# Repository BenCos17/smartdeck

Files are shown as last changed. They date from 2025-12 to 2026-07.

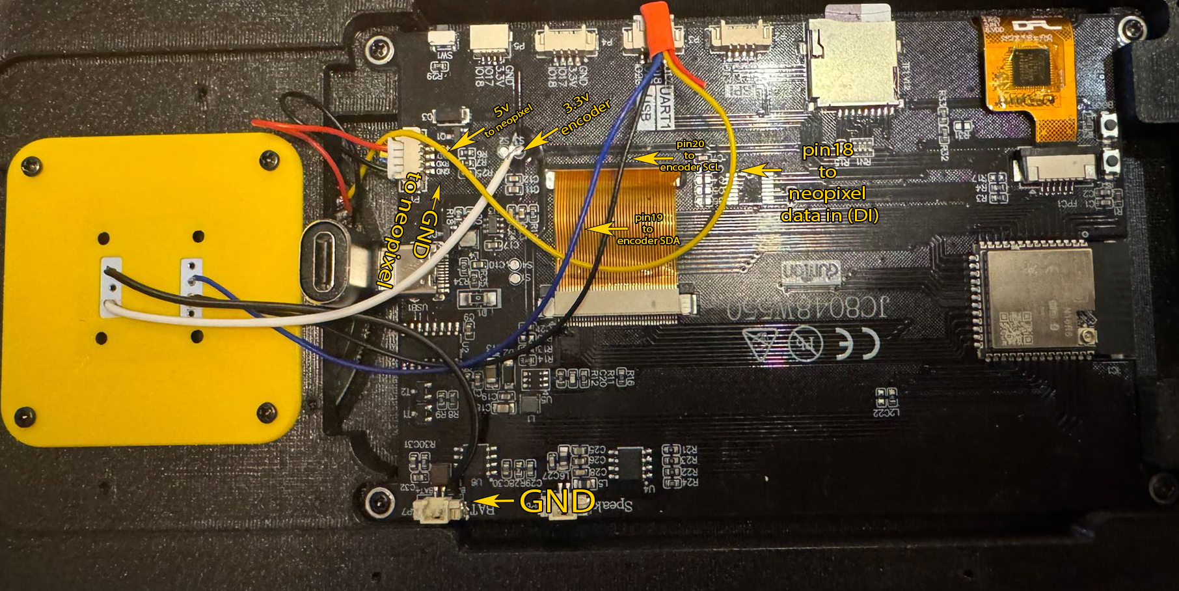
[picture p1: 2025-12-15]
wiring_scheme.jpg

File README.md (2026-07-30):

# SmartDeck v2.5.1

Ekran görüntüsü 2025-12-06 211021

<div align="center">

**A powerful, customizable macro deck application for Windows**



</div>

---

## 📖 Overview

SmartDeck transforms ESP32-based touch screens into powerful macro control panels. Create custom buttons to execute keyboard shortcuts, launch applications, control media, run scripts, build multi-action sequences, and much more. Perfect for streamers, content creators, developers, and power users.

---

## 🖥️ Supported Devices

| Device | Description |
|---|---|
| **ESP32 TouchDown** | 3.5" 480×320 ILI9488 + FT6236, ESP32-WROOM-32D ([Tindie](https://www.tindie.com/products/dustinwattsnl/esp32-touchdown/)) — **default in this fork** |
| **Guition JC8048W550** | 5" 800×480 Capacitive, ESP32-S3 ([AliExpress](https://www.aliexpress.us/item/3256806529267135.html)) |

> This fork ships with **`ESP32_TOUCHDOWN`** enabled in `JC8048W550/Arduino/smart_deck/config.h`. Set resolution to **480×320** in the SmartDeck desktop app.

> ⚠️ **Backlight (TouchDown V1.1)**: Bridge the backlight jumper to **GPIO32** on the board back if you want PWM brightness control. Without it, the screen stays on at full brightness.

> ⚠️ **JC8048W550**: SmartDeck is also optimized for the **Guition JC8048W550** display. 3D printed enclosure files and rotary encoder mounting are tailored for that device.

### 🔧 Adapting for Other Displays

SmartDeck is open source and can be adapted for other ESP32-based displays. To use a different screen:

1. Download the Arduino source files from this repository
2. Install **ESP32 Board Package v2.0.17** in Arduino IDE
3. Modify the following files for your display:
   - `config.h` - Uncomment your board (`ESP32_TOUCHDOWN`, `ESP32_JC8048W550`, etc.), set resolution and pins
   - `Arduino_GFX_dev_device.h` - Display driver and initialization settings
4. Compile and upload to your device

### ESP32 TouchDown quick start

1. Open `JC8048W550/Arduino/smart_deck/smart_deck.ino` in Arduino IDE
2. Board: **ESP32 Dev Module**, USB CDC disabled, 115200 baud
3. `config.h` should have `#define ESP32_TOUCHDOWN` (already set in this fork)
4. Upload firmware, then in SmartDeck app set device resolution to **480×320**

> 💡 Community contributions for other displays are welcome! If you successfully adapt SmartDeck for a different screen, consider submitting a PR.

---

## 🛒 Bill of Materials (BOM)

> ⚠️ **Note**: The following parts are required to build the complete SmartDeck with rotary encoder. The display itself is sold separately - see "Supported Devices" above.

| Part | Description | Link |
|---|---|---|
| **Guition JC8048W550** | 5" ESP32-S3 Capacitive Display (Main unit) | [AliExpress](https://www.aliexpress.us/item/3256806529267135.html) |
| **AS5600 Magnetic Encoder** | Rotary encoder module with magnet included | [AliExpress](https://tr.aliexpress.com/item/1005009252608246.html) |
| **NeoPixel RGB LED Ring** | 16-LED WS2812 ring (53mm inner, 66mm outer) | [AliExpress](https://tr.aliexpress.com/item/33039423907.html) |
| **25×52×15 Ball Bearing** | Deep-groove ball bearing for smooth rotation | [Link](https://simmering.pl/en/deep-groove-ball-bearings/28183-6205-zz-nectech-25x52x15-deep-groove-ball-bearing.html) |
| **6×3mm Neodymium Magnets** | Round magnets for encoder (80-150 pcs) | [Temu](https://www.temu.com/tr/80-150pcs-6x3mm-round-magnets-strong-neodymium--mini-refrigerator-whiteboard-magnets-durable-metal-construction-for-office-kitchen-fridge-org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) |
| **1.25mm to Dupont Cable** | 4-pin cable for 5V, GND, external pins (2 pcs) | [AliExpress](https://tr.aliexpress.com/item/1005006621865408.html) |
| **90° USB-C Adapter** | Right-angle Type-C male to female (40Gbps preferred) | [AliExpress](https://tr.aliexpress.com/item/1005006997812852.html) |
| **Screws** | Assorted screws for assembly | [Temu](https://www.temu.com/goods.html?_bg_fs=1&goods_id=601099519474986&sku_id=17592228808109) / [AliExpress](https://www.aliexpress.us/item/3256804422855415.html) |
| **Cables & Wires** | General-purpose wires for connections | — |
| **Soldering Iron** | For wiring and assembly | — |
| **Tape** | Insulation tape for cable management | — |

### 🖨️ 3D Printed Parts

STL files for the enclosure are available in the `/3d_print_files` folder.

---
WhatsApp Image 2025-12-06 at 21 16 12

## ✨ Key Features

### 🎮 **13 Button Action Types**

Ekran görüntüsü 2025-12-06 211035

| Action | Description |
|---|---|
| **HotKey** | Keyboard shortcuts (CTRL+C, ALT+TAB, etc.) |
| **Page** | Navigate between button pages |
| **Toggle** | Two-state buttons with visual feedback |
| **Text** | Type text with optional realistic typing simulation |
| **Open App** | Launch applications |
| **Timer** | Countdown timers with notifications |
| **Script** | Execute command-line scripts |
| **Website** | Open URLs in browser |
| **Media** | Play/pause, volume, track controls |
| **Mouse** | Click, double-click, move, drag |
| **Counter** | Increment/decrement with long-press reset |
| **Sound** | Play audio files with volume control |
| **Multi-Action** | Chain multiple actions in sequence |

### 🔗 **Multi-Action Builder**

Create complex macros by chaining actions together:

- **Delay** - Wait between actions (ms precision)
- **HotKey** - Press key combinations
- **Text** - Type text strings
- **Open App** - Launch programs
- **Website** - Open URLs
- **Script** - Run commands
- **Media** - Media controls
- **Sound** - Play audio
- **Mouse** - Mouse operations
- **Go to Page** - Switch pages

Drag & drop interface for easy sequence building.

### 🎛️ **Rotary Encoder Support**

- Volume control, scrolling, zooming
- Customizable actions for clockwise/counter-clockwise
- LED color feedback per page
- Adjustable sensitivity
- Modifier key combinations (ALT+Scroll, CTRL+Scroll)

### 🎨 **Full Customization**

- **100,000+ Icons** via Iconify integration
- **Local Images** with built-in crop & scale editor
- **Custom Colors** for background, text, icon, stroke, shadow
- **Text Positioning** - Top, middle, bottom alignment
- **Per-Button Styling** - Every button fully customizable

### 🌍 **7 Languages**

English • Türkçe • Deutsch • Español • Français • 日本語 • 中文

### ⚡ **Smart Features**

- **Auto-Connect** - Automatic device detection and reconnection
- **Smart Upload** - Only uploads changed files (faster sync)
- **App-Based Pages** - Auto-switch pages based on active application
- **Sleep/Wake** - Configurable screen timeout with tap-to-wake
- **Preview Mode** - Test buttons without device (right-click → Test)
- **Undo/Redo** - Full history with up to 50 steps
- **Drag & Drop** - Reorder buttons and pages intuitively
- **System Tray** - Minimize to tray, start minimized option

### 📦 **Built-in Presets**

Ready-to-use shortcuts for:

- Adobe Suite (Photoshop, Premiere, After Effects, Illustrator)
- 3D Software (Blender, Cinema 4D)
- DAWs (FL Studio, DaVinci Resolve)
- Streaming (OBS Studio)
- Development (VS Code)
- General (Chrome, Discord, VLC, Spotify)

---

## 🚀 Getting Started

### Requirements

- Windows 10/11
- Guition JC8048W550 (or compatible ESP32 display)

### Installation

1. Download latest release from [Releases](https://github.com/ozancs/smartdeck/releases)
2. Run installer
3. Connect device via USB
4. Flash firmware using **⚡ Install Firmware** button
5. Start creating!

---

## 🔧 How It Works

```
┌─────────────────┐     USB/Serial     ┌──────────────────┐
│  SmartDeck App  │ ◄───────────────► │  ESP32 Device    │
│  (Electron)     │    115200 baud     │  (Touch Screen)  │
└─────────────────┘                    └──────────────────┘
        │                                       │
        ▼                                       ▼
   Button Config                          Display & Touch
   Action Execute                         Button Rendering
   Serial Commands                        Touch Events
```

### Connection Flow

1. App scans for COM ports automatically
2. Sends PING, waits for PONG handshake
3. Syncs configuration to device
4. Receives touch events in real-time
5. Auto-reconnects on disconnect

---

## ⚙️ Settings

Ekran görüntüsü 2025-12-06 211042

| Category | Options |
|---|---|
| **Device** | Name, resolution, grid size, colors |
| **Screen** | Brightness, sleep timeout |
| **Knob** | LED colors per page, sensitivity, actions |
| **Startup** | Launch with Windows, start minimized |
| **Close** | Exit or minimize to tray |
| **Sound** | Toggle sound, timer notification |
| **Language** | 7 language options |

---

## 🛠️ Firmware Installation

1. Click **⚡ Install Firmware**
2. Select screen model
3. Choose COM port
4. Click **START FLASHING**
5. Wait for completion (~60 seconds)

> ⚠️ Do not unplug during flashing!

---

## 📝 What's New in v2.5.1

- ✅ Multi-Action Builder with drag & drop
- ✅ Rotary encoder support with LED feedback
- ✅ Preview/Test mode (right-click menu)
- ✅ Start minimized to system tray
- ✅ Unicode path support (Turkish characters, etc.)
- ✅ App-based automatic page switching
- ✅ Smart upload (only changed files)
- ✅ Serial debug monitor
- ✅ Improved auto-reconnect stability
- ✅ Full internationalization for all UI elements

---

## 🤝 Contributing

Contributions welcome! 

- **Bug Reports**: Open an issue with reproduction steps
- **Feature Requests**: Describe your idea in an issue
- **New Device Support**: Fork, adapt firmware, submit PR

## 📄 License

This project is open source. See [LICENSE](LICENSE) for details.

## 🙏 Acknowledgments

- [Iconify](https://iconify.design/) - Icon library
- [NirCmd](https://www.nirsoft.net/utils/nircmd.html) - Audio control utilities
- [Electron](https://www.electronjs.org/) - Application framework
- [@jitsi/robotjs](https://github.com/nicktgr15/robotjs) - Keyboard/mouse automation

---

<div align="center">

**[⬇️ Download](https://github.com/ozancs/smartdeck/releases)** • **[🐛 Report Bug](https://github.com/ozancs/smartdeck/issues)** • **[💡 Request Feature](https://github.com/ozancs/smartdeck/issues)**

Made with ❤️ by [ozancs](https://github.com/ozancs)

</div>

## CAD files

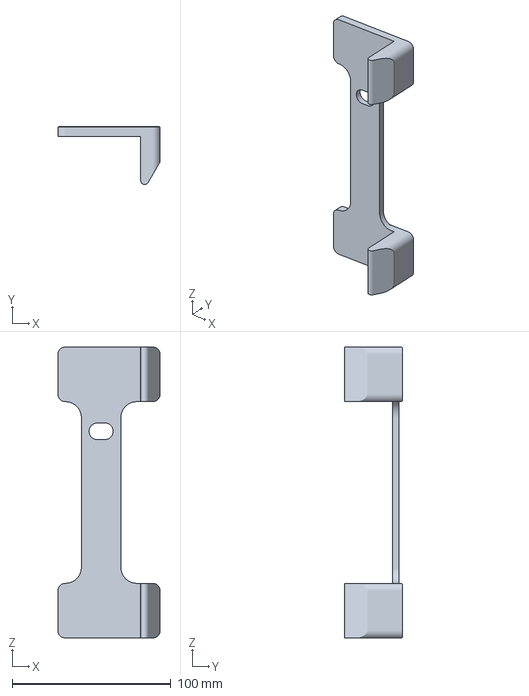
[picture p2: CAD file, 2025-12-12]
3d_print_files/60_DEGREE_LEG.3mf
64.5 x 36.7 x 183.5 mm

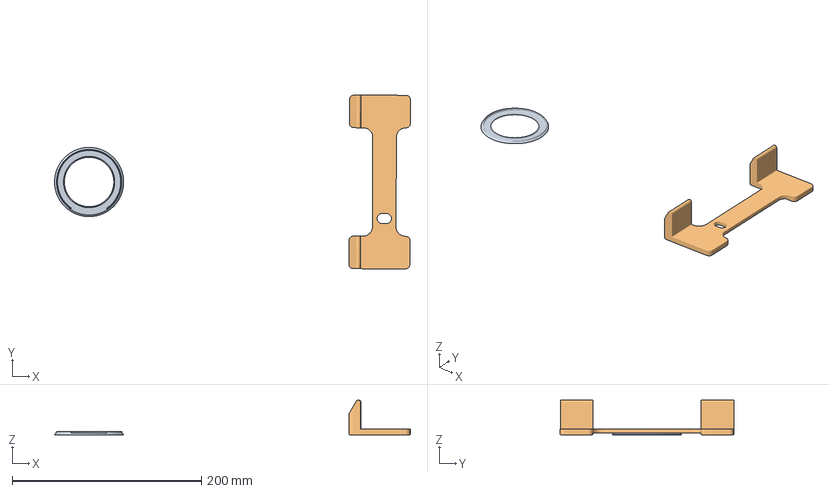
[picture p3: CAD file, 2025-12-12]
3d_print_files/diffuser.3mf
376.3 x 183.7 x 36.7 mm
diffuser
30degree_holder

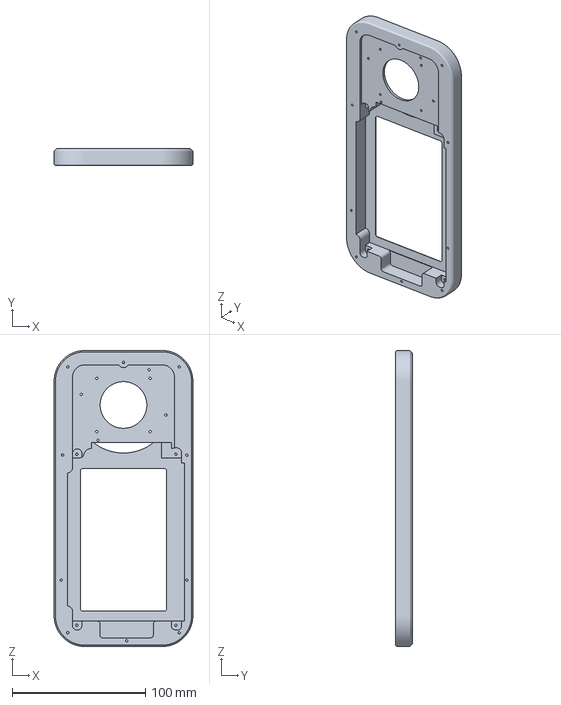
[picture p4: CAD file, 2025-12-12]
3d_print_files/Body.3mf
104.0 x 13.0 x 222.0 mm

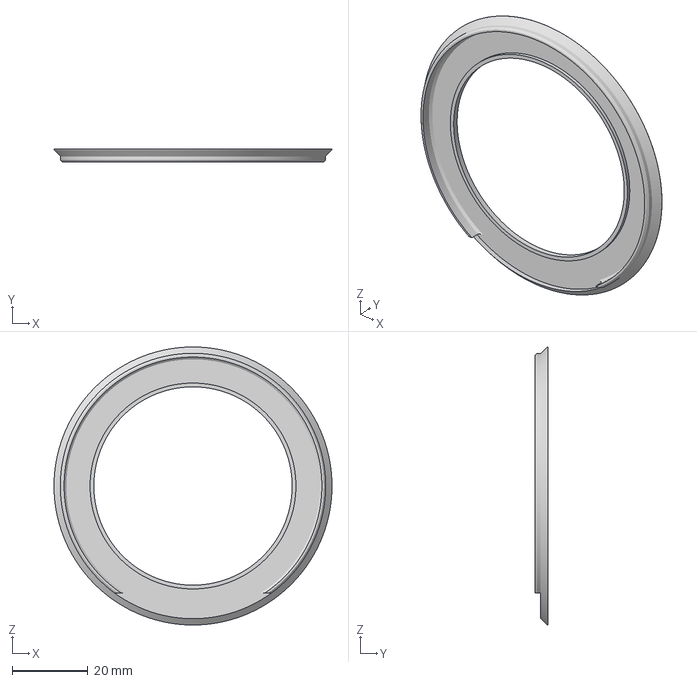
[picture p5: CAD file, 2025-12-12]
3d_print_files/diffuser_0.4mm.3mf
73.2 x 3.50 x 73.2 mm

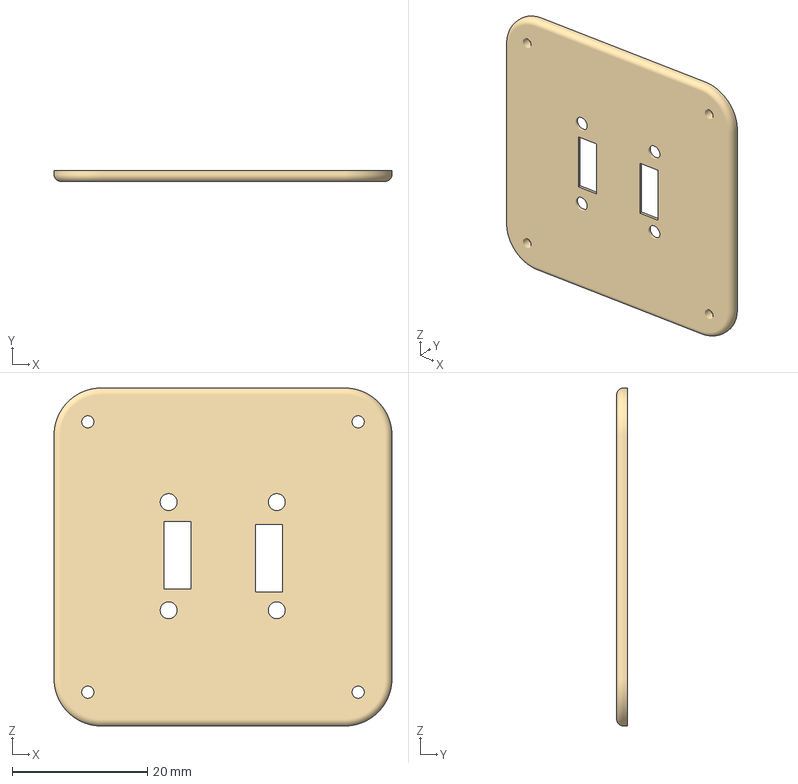
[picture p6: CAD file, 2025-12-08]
3d_print_files/as5600_holder.3mf
50.0 x 1.60 x 50.0 mm

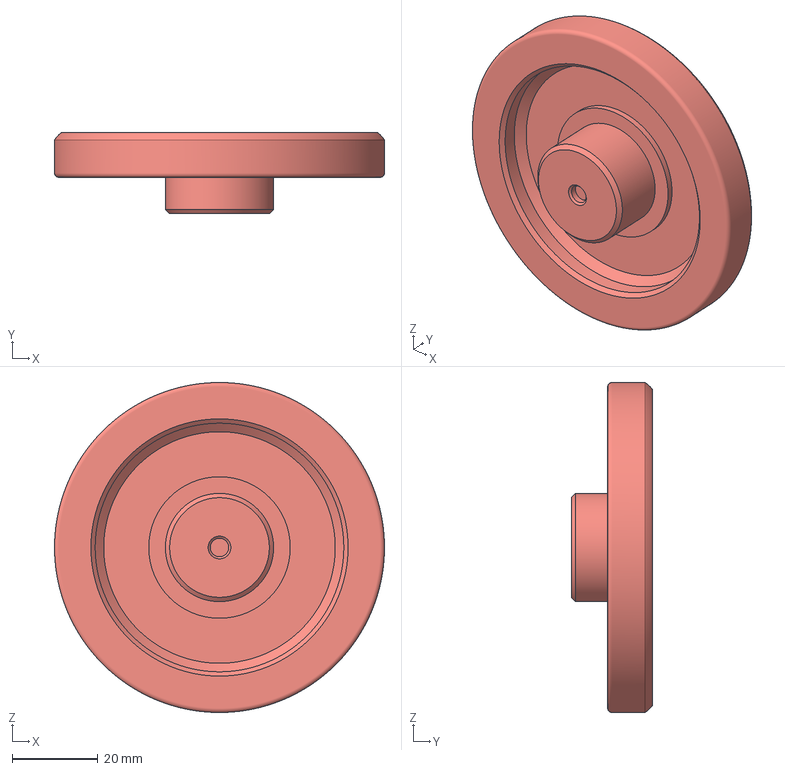
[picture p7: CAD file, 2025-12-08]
3d_print_files/Knob.3mf
77.0 x 19.0 x 77.0 mm

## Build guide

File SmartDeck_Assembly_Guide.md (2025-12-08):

# SmartDeck Hardware Assembly Guide

## Prerequisites

### 3D Printed Parts
Print all parts from the `3D Print Files` folder with the following settings:
- **Supports:** Enabled (required for overhangs)
- **Infill:** 15-20% recommended
- **Layer Height:** 0.2mm or finer for better tolerances

**Parts List:**
- Main Body (1x)
- Knob (1x)
- AS5600 Holder (1x)
- Back Cover (1x)
- Stand/Feet (optional, 1x)

### Bill of Materials

| Item | Description | Source |
|---|---|---|
| 25×52×15 Ball Bearing | Deep-groove ball bearing | [Link](https://simmering.pl/en/deep-groove-ball-bearings/28183-6205-zz-nectech-25x52x15-deep-groove-ball-bearing.html) |
| AS5600 Magnetic Encoder Module | Includes matching magnet | [Link](https://tr.aliexpress.com/item/1005009252608246.html) |
| NeoPixel RGB LED Ring (16 LEDs) | WS2812-compatible, ~53mm inner / ~66mm outer diameter | [Link](https://tr.aliexpress.com/item/33039423907.html) |
| 90° Type-C Male to Female Adapter | Prefer "40Gbps" printed version | [Link](https://tr.aliexpress.com/item/1005006997812852.html) |
| 6×3mm Round Neodymium Magnets | 80-150 pieces for back cover and stand | [Link](https://www.temu.com/tr/80-150pcs-6x3mm-round-magnets-strong-neodymium--mini-refrigerator-whiteboard-magnets-durable-metal-construction-for-office-kitchen-fridge-org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) |
| 1.25mm to Dupont 2.54 Terminal Cable (4-Pin) | For display connector routing (optional) | [Link](https://tr.aliexpress.com/item/1005006621865408.html) |
| M2 Screws | Various lengths: M2×3mm, M2×4mm, M2×5mm | [Link 1](https://www.temu.com/goods.html?_bg_fs=1&goods_id=601099519474986&sku_id=17592228808109) / [Link 2](https://www.aliexpress.us/item/3256804422855415.html) |
| Soldering Iron | For wiring connections | — |
| Cables/Wires | For external connections | — |
| Tape | Electrical or general-purpose | — |

---

## Assembly Instructions

### Step 1: Prepare the Knob Assembly

1. **Install the ball bearing:**
   - Press the **25×52×15mm ball bearing** into the knob print until it sits flush.
   - It should be a snug fit; apply even pressure around the edges.

2. **Attach the magnet:**
   - Locate the small hole on the underside of the knob (center).
   - Take the **magnet included with the AS5600 module** and apply a small amount of adhesive to its back only (the side that will contact the knob).
   - **Important:** Keep the face of the magnet that will face the sensor completely free of adhesive. Any glue residue on this surface can cause signal fluctuations and erratic readings.
   - Press the magnet into the hole and allow it to cure.

---

### Step 2: Prepare the SD Card

The ESP32 display requires a FAT32-formatted SD card.

1. Insert your SD card into your computer.
2. Format it as **FAT32**.

> **Note for large capacity cards (64GB+):** Windows cannot natively format cards larger than 32GB as FAT32. Use the free tool **guiformat** from:
> http://ridgecrop.co.uk/index.htm?guiformat.htm

3. Once formatted, insert the SD card into the display's SD card slot.

---

### Step 3: Mount the Display

1. Attach the **90° Type-C adapter** to the display's USB-C port.
2. Place the display into the main body with the USB connector oriented toward the knob side.
3. Align the four mounting holes and secure with **M2×4mm or M2×5mm screws** (the screw holes are approximately 5mm deep).

---

### Step 4: Install the NeoPixel LED Ring

1. **Solder wires to the LED ring:**
   - Solder individual wires to the **5V**, **GND**, and **DI (Data In)** pads.
   - Cut wires longer than needed; you can trim them later.

2. **Mount the ring:**
   - Route the wires through the cable channel in the main body.
   - Press the **16-LED NeoPixel ring** into the knob-side recess, aligning the four screw holes.
   - Secure with **M2×3mm or M2×3.5mm screws** (hole depth is ~7.5mm; do not exceed this).

---

### Step 5: Prepare and Install the AS5600 Encoder Module

1. **Solder wires to the AS5600 module:**
   - Attach wires to: **SDA**, **SCL**, **VCC**, and **GND** pads.

2. **Mount the module in its holder:**
   - Insert the AS5600 module into the **AS5600 Holder** print with wires passing through the designated holes.
   - The fit should be snug. If there's slight play, use a small amount of adhesive to secure it.

3. **Install the holder in the main body:**
   - Position the holder inside the main body so the **sensor faces the knob hole** (where the magnet will be).
   - Secure with four **M2×5mm screws** (hole depth is ~7.5mm).

---

### Step 6: Clean the Main Body and Install the Knob

> **Important:** Before proceeding, thoroughly clean all support material residue from the main body, especially inside the bearing seat. Leftover supports can prevent proper seating and cause friction.

1. Take the knob assembly (with bearing and magnet installed).
2. Align it with the bearing seat on the main body.
3. Press firmly until the bearing snaps into place. It should rotate smoothly.

---

### Step 7: Prepare the Back Cover

1. Remove all support material from the back cover print.
2. Insert **6×3mm neodymium magnets** into each magnet slot.
   - **Critical:** Ensure all magnets have the **same polarity orientation** (e.g., all north-facing up).
   - Some holes may be tight due to printer tolerances; apply gentle pressure.
   - Some may be loose; proceed to the next step.
3. Once all magnets are seated, cover them with a strip of tape to prevent them from dislodging.

---

### Step 8: Prepare the Stand (Optional)

1. Insert **6×3mm neodymium magnets** into the stand's magnet slots.
2. **Critical:** These magnets must be in the **opposite orientation** to those in the back cover (so they attract, not repel).
3. Double-check each magnet before fully seating it. A reversed magnet will cause the stand and body to repel each other.
4. Secure with tape if needed.

---

### Step 9: Wiring Connections

You have two options for connecting the components to the display's GPIO pins:

| Method | Pros | Cons |
|---|---|---|
| **Soldering directly to pins** | Most reliable, clean | Requires soldering skill |
| **Dupont connectors** (included with display) | No soldering needed | Bulkier, may come loose |

**Recommended:** Direct soldering for best long-term reliability.

If you choose the Dupont connector method, you'll need to connect your soldered component wires to the Dupont cables. You can do this by twisting the wires together—this is the quickest solution but also the least clean. For a more secure connection, solder the component wires directly to the Dupont cable ends or use crimp connectors.

#### AS5600 Encoder Connections

| AS5600 Pin | ESP32 GPIO | Notes |
|---|---|---|
| SDA | Pin 19 | I²C Data |
| SCL | Pin 20 | I²C Clock |
| VCC | 3.3V | **Do not use 5V** |
| GND | GND | |

#### NeoPixel LED Ring Connections

| NeoPixel Pin | ESP32 GPIO | Notes |
|---|---|---|
| DI (Data In) | Pin 18 | Data signal |
| 5V | 5V | Power |
| GND | GND | |

---

### Step 10: Final Assembly

1. Route all wires neatly inside the enclosure.
2. Align the **back cover** with the USB cutout facing the correct direction.
3. Secure with **M2×5mm screws** into the main body.
4. Attach the **stand** to the back cover—the magnets should snap together satisfyingly.

---

## Software Setup

1. Connect SmartDeck to your computer via USB.
2. Download and install the **SmartDeck** application from:
   
   👉 **https://github.com/ozancs/smartdeck/releases**

3. Launch the application.
4. Click **"Install Firmware"** in the bottom-right corner.
5. Select your device's **COM port** from the dropdown.
6. Click **Install** to flash the firmware to your ESP32 display.
7. Once complete, configure your buttons, LED colors, themes, and macros.

---

**Enjoy your SmartDeck!**

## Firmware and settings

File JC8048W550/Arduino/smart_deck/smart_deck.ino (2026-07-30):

/* * OZAN'S WEB DECK - v4.0 (Serial and ESP-NOW Mode)
 * * This version does not include Wi-Fi and BLE. Communication is done via USB Serial Port
 * or ESP-NOW (Dongle Mode).
 * */
#ifndef BLACK
#define BLACK 0x0000
#endif

#ifndef WHITE
#define WHITE 0xFFFF
#endif


#include "config.h"

// Receiver MAC for ESP-NOW dongle mode
uint8_t receiver_mac[] = RECEIVER_MAC;

#include "touch_panel.h"

// --- REMOVED: <BleKeyboard.h> ---
// --- REMOVED: <WiFi.h>, <AsyncTCP.h>, <ESPAsyncWebServer.h>, <ESPmDNS.h> ---

#include <vector>
#include <map>
#include <string>
#include <set>
#include <ArduinoJson.h>

/* GFX Libraries */
#include <Arduino_GFX_Library.h>
#include "Arduino_GFX_dev_device.h"
#ifndef GFX_DEV_DEVICE
#include "Arduino_GFX_pins.h"
#include "Arduino_GFX_databus.h"
#include "Arduino_GFX_display.h"
#endif
#ifdef ESP32
#undef F
#define F(s) (s)
#endif

/* SD Card Libraries */
#include "FS.h"
#include "SD.h"
#include <SPI.h>

#include <Adafruit_NeoPixel.h>

// NeoPixel object
Adafruit_NeoPixel strip(LED_COUNT, LED_PIN, NEO_GRB + NEO_KHZ800);


/* --- TJpgDec Library --- */
#include <TJpg_Decoder.h>

/* --- Weather Icons for Sleep Screen --- */
#include "weather_icons.h"

/* --- NEW: For Saving Settings --- */
#include <Preferences.h>
Preferences preferences;

/* --- NEW: Brightness and Sleep Variables --- */
int current_brightness = 100;                    // 0-100 range
bool sleep_enabled = false;                      // Is sleep mode enabled?
unsigned long sleep_timeout_ms = 1 * 60 * 1000;  // Default 5 minutes
unsigned long last_activity_time = 0;            // Last activity time
bool is_sleeping = false;                        // Currently sleeping?

/* --- Clock for Sleep Mode (millis-based tracking) --- */
int current_hour = 12;
int current_minute = 0;
int current_second = 0;
unsigned long last_clock_update_millis = 0;  // Last time we updated the clock
bool clock_initialized = false;              // Has time been set at least once?

/* --- Weather Data for Sleep Screen --- */
bool weather_available = false;     // Do we have valid weather data?
int weather_temp = 0;               // Temperature (integer)
int weather_code = 0;               // WMO weather code
bool weather_is_day = true;         // Is it daytime?
bool weather_is_celsius = true;     // Temperature unit (true=C, false=F)
char weather_description[32] = "";  // Weather description from app (translated)
char weather_city[32] = "";         // City name from app

/* --- Deep Sleep Mode (screen & LED off) --- */
bool deep_sleep_enabled = false;                       // Is deep sleep enabled?
unsigned long deep_sleep_timeout_ms = 30 * 60 * 1000;  // Default 30 min after dim
unsigned long dim_start_time = 0;                      // When did dim mode start?
bool is_deep_sleeping = false;                         // Currently in deep sleep?

/* --- Dim LED Animation --- */
// 0=off, 1=breathing, 2=rainbow, 3=pulse, 4=comet, 5=sparkle
uint8_t dim_led_animation = 0;
unsigned long dim_led_last_update = 0;
uint16_t dim_led_step = 0;
uint8_t dim_led_hue = 0;

// Rainbow animation color
uint8_t fade_color_r = 255, fade_color_g = 0, fade_color_b = 0;

// Sparkle state - tracks which LEDs are blinking and their phase
uint8_t sparkle_brightness[LED_COUNT];
bool sparkle_active[LED_COUNT];

#include <Wire.h>
#include <AS5600.h>

AS5600 as5600(&Wire);

// Knob LED settings
int knob_old_angle = 0;
int knob_threshold = KNOB_THRESHOLD;
unsigned long lastKnobEvent = 0;
uint8_t knob_r = 255, knob_g = 255, knob_b = 255;  // Default: White
int knob_tail_length = 5;
uint8_t led_brightness = 255;  // LED brightness (0-255)


// --- CONDITIONAL LIBRARY INCLUSION (Only for Dongle Mode) ---
#if DONGLE_MODE == 1
#include <WiFi.h>  // Required for ESP-NOW
#include <esp_now.h>
#endif
// --- END ---

// Touch Panel
#if defined(ESP32_TOUCHDOWN)
TouchPanel tp(TOUCH_SDA, TOUCH_SCL, TOUCH_INT, TOUCH_WIDTH, TOUCH_HEIGHT);
#else
TouchPanel tp(TOUCH_SDA, TOUCH_SCL, TOUCH_INT, TOUCH_RST, TOUCH_WIDTH, TOUCH_HEIGHT);
#endif

/*******************************************************************************
 * Global Variables
 ******************************************************************************/
uint32_t screenWidth = SCREEN_WIDTH;
uint32_t screenHeight = SCREEN_HEIGHT;

/* REMOVED: BleKeyboard bleKeyboard; */
/* REMOVED: AsyncWebServer server(80); */
/* REMOVED: String ip_address = "Connecting..."; */
/* REMOVED: File uploadFile; */

String serial_cmd_buffer = "";
bool serial_cmd_ready = false;

DynamicJsonDocument doc(16384);
uint8_t current_page = 0;
uint16_t theme_bg_color_rgb565;
uint16_t theme_btn_color_rgb565;
uint16_t theme_stroke_color_rgb565 = 0x8410;
uint16_t theme_empty_btn_color_rgb565 = 0x3186;
uint16_t theme_click_stroke_color_rgb565 = 0x05BF;
uint16_t theme_text_color_rgb565;
uint16_t theme_shadow_color_rgb565;

struct ButtonInfo {
  int x;
  int y;
  int w;
  int h;
  String action;
  String value;
  bool defined = false;
};
std::vector<ButtonInfo> current_buttons;

enum TimerState {
  TIMER_INACTIVE,
  TIMER_RUNNING,
  TIMER_FINISHED
};
struct TimerInfo {
  TimerState state = TIMER_INACTIVE;
  int duration = 0;
  unsigned long startTime = 0;
  int lastSeconds = -1;  // Last displayed seconds
};

// Global map for running timers (survives page changes)
// Key: page * 100 + btn_idx
std::map<int, TimerInfo> running_timers;

// Global map for finished timers (waiting for auto-reset on other pages)
// Key: page * 100 + btn_idx, Value: {finish_time, duration}
struct FinishedTimerInfo {
  unsigned long finishTime;
  int duration;
};
std::map<int, FinishedTimerInfo> finished_timers;

struct CounterInfo {
  long currentValue = 0;        // Current counter value
  long startValue = 0;          // Start value (for reset)
  String action = "increment";  // "increment" or "decrement"
};
std::vector<CounterInfo> current_counters;  // <-- NEWLY ADDED

// --- NEW: TOGGLE INFO ---
struct ToggleInfo {
  bool state = false;         // false = OFF (State A), true = ON (State B)
  uint16_t onColor = 0x07E0;  // Default Green (RGB565)
};
std::vector<ToggleInfo> current_toggles;

std::vector<TimerInfo> current_timers;

bool was_touched = false;
int last_touched_button_index = -1;
unsigned long touch_start_time = 0;  // NEW: For detecting long press
bool long_press_triggered = false;   // NEW: Was long press triggered?

typedef struct {
  int x;
  int y;
  int maxWidth;
  int maxHeight;
  int x_offset;
  int y_offset;
  int radius;
} JpegDrawInfo;

JpegDrawInfo jpegInfo;


// --- FUNCTION PROTOTYPES (Prevents compiler errors) ---
void draw_page(int page_index);
void draw_single_button(int btn_index);
void checkActiveTimers();


// *** NEW: Send Command to PC/Dongle Function (State Supported) ***
void send_pc_command(int page, int index) {
  char command[64];

  // Check if button is Toggle
  if (current_buttons[index].action == "toggle") {
    // If Toggle: BTN:Page:Index:State (e.g: BTN:0:14:1)
    int stateVal = current_toggles[index].state ? 1 : 0;
    sprintf(command, "BTN:%d:%d:%d\n", page, index, stateVal);
  } else {
    // If normal button, use old format: BTN:Page:Index
    sprintf(command, "BTN:%d:%d\n", page, index);
  }

#if DONGLE_MODE == 1
  // Send via ESP-NOW
  esp_now_send(receiver_mac, (uint8_t*)command, strlen(command) + 1);
#else
  // Send via USB Serial
  Serial.printf("%s", command);
#endif
}
// *** NEW: Brightness Adjustment Function ***
// *** FIXED: Brightness Adjustment Function ***
// *** FIXED: Gamma (Perceptual) Brightness Function ***
#include <math.h>  // May be needed for pow function, usually embedded in Arduino but just to be sure.

// *** FIXED: Smoother Transition Brightness Function ***
#include <math.h>

// *** FIXED (V3): Linear and Stable Brightness ***
void set_brightness(int percent) {
  // Safety check
  if (percent < 0) percent = 0;
  if (percent > 100) percent = 100;

  current_brightness = percent;

  int duty = 0;

  if (percent == 0) {
    duty = 0;  // Completely off
  } else if (percent == 100) {
    duty = 255;  // Completely on
  } else {
    // HARDWARE LIMIT UPDATE
    // If your screen turns off below 85, your lower limit is too high.
    // 235 out of 255 is approximately 92% power.
    // We're mapping slider's 1% to this 235.

    int min_hardware_limit = 30;
    int max_hardware_limit = 255;

    duty = map(percent, 1, 100, min_hardware_limit, max_hardware_limit);
  }

#ifdef GFX_BL
  ledcWrite(BL_PWM_CHANNEL, duty);
#endif
}

// Forward declarations for sleep screen functions
void drawWeatherIcon(int x, int y, const uint16_t* icon);
const char* getWeatherDescription(int code);

// *** NEW: Activity Update (Wake Up) ***
void update_activity() {
  last_activity_time = millis();

  // Wake from deep sleep
  if (is_deep_sleeping) {
    is_deep_sleeping = false;
    is_sleeping = false;

    // Turn on LEDs
    strip.setBrightness(255);
    strip.show();

    // Restore screen
    gfx->fillScreen(BLACK);
    set_brightness(current_brightness);
    draw_page(current_page);
    Serial.println("[Deep Sleep] Woke up from deep sleep");
    return;
  }

  // Wake from dim sleep
  if (is_sleeping) {
    is_sleeping = false;
    dim_start_time = 0;  // Reset dim timer
    // CRITICAL FIX: First clear screen, then restore brightness, then draw page
    // This prevents the sleep clock from flashing briefly
    gfx->fillScreen(BLACK);
    set_brightness(current_brightness);
    draw_page(current_page);
  }
}

void check_sleep_mode() {
  // Deep sleep check (screen & LEDs completely off)
  if (is_deep_sleeping) {
    return;  // Already in deep sleep, do nothing
  }

  // Check for deep sleep transition (after dim period)
  if (is_sleeping && deep_sleep_enabled && dim_start_time > 0) {
    if (millis() - dim_start_time > deep_sleep_timeout_ms) {
      is_deep_sleeping = true;

// Turn off screen completely
#ifdef GFX_BL
      ledcWrite(BL_PWM_CHANNEL, 0);
#endif
      gfx->fillScreen(BLACK);

      // Turn off LEDs
      strip.clear();
      strip.show();

      Serial.println("[Deep Sleep] Entered deep sleep mode");
      return;
    }
  }

  // Normal sleep (dim) check
  if (is_sleeping) {
    // Run dim LED animation if enabled
    run_dim_led_animation();
    return;  // Already in dim mode
  }

  if (!sleep_enabled) return;

  if (millis() - last_activity_time > sleep_timeout_ms) {
    is_sleeping = true;
    dim_start_time = millis();  // Start deep sleep timer

    // CRITICAL: Reset strip brightness for animations
    strip.setBrightness(led_brightness);

    // Reset animation state - start from DARKEST point (270)
    dim_led_step = 270;  // Start at minimum brightness
    dim_led_hue = 0;
    dim_led_last_update = 0;  // Force immediate update

    // Set initial random color for rainbow
    uint8_t colorChoice = random(8);
    switch (colorChoice) {
      case 0:
        fade_color_r = 255;
        fade_color_g = 0;
        fade_color_b = 0;
        break;
      case 1:
        fade_color_r = 255;
        fade_color_g = 100;
        fade_color_b = 0;
        break;
      case 2:
        fade_color_r = 255;
        fade_color_g = 255;
        fade_color_b = 0;
        break;
      case 3:
        fade_color_r = 0;
        fade_color_g = 255;
        fade_color_b = 0;
        break;
      case 4:
        fade_color_r = 0;
        fade_color_g = 255;
        fade_color_b = 255;
        break;
      case 5:
        fade_color_r = 0;
        fade_color_g = 100;
        fade_color_b = 255;
        break;
      case 6:
        fade_color_r = 150;
        fade_color_g = 0;
        fade_color_b = 255;
        break;
      case 7:
        fade_color_r = 255;
        fade_color_g = 0;
        fade_color_b = 150;
        break;
    }

    // Reset sparkle arrays and clear all LEDs
    for (int i = 0; i < LED_COUNT; i++) {
      sparkle_brightness[i] = 0;
      sparkle_active[i] = false;
      strip.setPixelColor(i, 0);  // Clear all LEDs
    }
    strip.show();

    // Request time from PC if not initialized
    if (!clock_initialized) {
      Serial.println("GET_TIME");
    }

    // Dim the screen
#ifdef GFX_BL
    // Use ~30% brightness for sleep mode
    ledcWrite(BL_PWM_CHANNEL, 80);
#endif

    // Clear screen and draw clock
    gfx->fillScreen(BLACK);
    draw_sleep_clock();
  }
}

// ============================================================================
// DIM LED ANIMATIONS
// ============================================================================
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
void loop() {
  unsigned long currentMillis = millis();

  // ============================================================
  // 0. INTERNAL CLOCK UPDATE (millis-based)
  // ============================================================
  if (clock_initialized && currentMillis - last_clock_update_millis >= 1000) {
    // Update every second
    unsigned long elapsed_seconds = (currentMillis - last_clock_update_millis) / 1000;
    last_clock_update_millis = currentMillis;

    current_second += elapsed_seconds;
    while (current_second >= 60) {
      current_second -= 60;
      current_minute++;
      if (current_minute >= 60) {
        current_minute = 0;
        current_hour++;
        if (current_hour >= 24) {
          current_hour = 0;
        }
      }
      // Update sleep clock if minute changed
      if (is_sleeping) {
        draw_sleep_clock();
      }
    }
  }

  // ============================================================
  // 1. KNOB READING AND LED MANAGEMENT (BREATH + COMET)
  // ============================================================
  if (currentMillis - lastLedUpdate >= LED_INTERVAL) {
    lastLedUpdate = currentMillis;

    // A) Knob Verisini Oku
    int rawAngle = as5600.readAngle();

    // Deep sleep'te knob hareketiyle uyan
    static int lastKnobAngle = 0;
    if (is_deep_sleeping) {
      int angleDiff = abs(rawAngle - lastKnobAngle);
      // Handle wrap-around (4096 -> 0)
      if (angleDiff > 2048) angleDiff = 4096 - angleDiff;

      if (angleDiff > KNOB_THRESHOLD * 2) {  // Biraz daha büyük eşik
        update_activity();                   // Wake up from deep sleep
        lastKnobAngle = rawAngle;
        return;  // Skip LED update this cycle
      }
      lastKnobAngle = rawAngle;
      return;  // Deep sleep'te LED güncelleme yapma
    }
    lastKnobAngle = rawAngle;

    strip.clear();

    // B) MODE CHECK: SLEEP OR ACTIVE?
    if (is_sleeping) {
      // --- BREATHING MODE ---
      // Calculate brightness using sine wave (smooth cyclic transition)
      float breath = (exp(sin(millis() / 2000.0 * PI)) - 0.36787944) * 108.0;
      int bVal = (int)breath;
      if (bVal < 0) bVal = 0;
      if (bVal > 255) bVal = 255;

      // Adjust color brightness based on breath value
      uint8_t r = (knob_r * bVal) / 255;
      uint8_t g = (knob_g * bVal) / 255;
      uint8_t b = (knob_b * bVal) / 255;

      // Light all LEDs
      for (int i = 0; i < strip.numPixels(); i++) {
        strip.setPixelColor(i, strip.Color(r, g, b));
      }

    } else {
      // --- ACTIVE MODE (SMOOTH COMET TAIL) ---
      // Calculate float position (0.0 - LED_COUNT)
      float ledPosFloat = (rawAngle / 4096.0f) * (float)LED_COUNT;

      // Apply LED offset (degrees to LED position)
      float offsetLeds = (float)LED_OFFSET / 360.0f * (float)LED_COUNT;
      ledPosFloat += offsetLeds;
      while (ledPosFloat >= (float)LED_COUNT) ledPosFloat -= (float)LED_COUNT;
      while (ledPosFloat < 0.0f) ledPosFloat += (float)LED_COUNT;

      // If tail is LED_COUNT, all LEDs light equally
      if (knob_tail_length >= LED_COUNT) {
        for (int i = 0; i < LED_COUNT; i++) {
          strip.setPixelColor(i, strip.Color(knob_r, knob_g, knob_b));
        }
      } else {
        // Calculate brightness for each LED
        for (int i = 0; i < LED_COUNT; i++) {
          // Calculate distance between this LED and head position
          float dist = ledPosFloat - (float)i;

          // Wrap-around: keep between 0 and LED_COUNT
          while (dist < 0.0f) dist += (float)LED_COUNT;
          while (dist >= (float)LED_COUNT) dist -= (float)LED_COUNT;

          float brightness = 0.0f;
          float tailF = (float)knob_tail_length;
          float ledCountF = (float)LED_COUNT;

          // Leading LED - gradually brighten
          if (dist > ledCountF - 1.0f) {
            brightness = dist - (ledCountF - 1.0f);  // (LED_COUNT-1)→0, LED_COUNT→1
            brightness = brightness * brightness;
          }
          // Kuyruk LED'leri - ana bölge
          else if (dist < tailF) {
            float fadeRatio = dist / tailF;
            brightness = 1.0f - (fadeRatio * fadeRatio * 0.9f);  // Quadratic, min %10
          }
          // Kuyruk sonu - smooth fade out (1 LED ekstra)
          else if (dist < tailF + 1.0f) {
            float fadeOut = tailF + 1.0f - dist;    // 1→0
            brightness = fadeOut * fadeOut * 0.1f;  // Quadratic fade to 0
          }

          // Parlaklık uygula
          if (brightness > 0.01f) {
            int bVal = (int)(brightness * 255.0f);
            if (bVal > 255) bVal = 255;

            uint8_t r = (knob_r * bVal) / 255;
            uint8_t g = (knob_g * bVal) / 255;
            uint8_t b = (knob_b * bVal) / 255;

            strip.setPixelColor(i, strip.Color(r, g, b));
          }
        }
      }
    }
    strip.show();

    // C) Hareket Algılama ve RAW Açı Gönderme
    int delta = rawAngle - knob_old_angle;
    if (delta > 2048) delta -= 4096;
    else if (delta < -2048) delta += 4096;

    // Minimal gürültü filtresi - sadece 3 birimden fazla hareket varsa gönder
    if (abs(delta) > 3) {
      update_activity();
      Serial.printf("KNOB_RAW:%d\n", rawAngle);
      knob_old_angle = rawAngle;
    }
  }

  // ============================================================
  // 2. SERİ PORT KOMUTLARI (PC'den Gelenler)
  // ============================================================
  if (Serial.available() > 0) {
    String command = Serial.readStringUntil('\n');
    command.trim();

    if (command.length() > 0) {

      // --- Parlaklık ---
      if (command.startsWith("SET_BRIGHTNESS:")) {
        int val = command.substring(15).toInt();
        set_brightness(val);
        preferences.putInt("bright", val);
        Serial.printf("Brightness set to %d%%\n", val);
        update_activity();
      }

      if (command.startsWith("SWAP_BTN:")) {
        int first = command.indexOf(':');
        int second = command.indexOf(':', first + 1);
        int third = command.indexOf(':', second + 1);

        if (first > 0 && second > 0 && third > 0) {
          int page = command.substring(first + 1, second).toInt();
          int fromIdx = command.substring(second + 1, third).toInt();
          int toIdx = command.substring(third + 1).toInt();

          // Validate page and index
          if (page >= 0 && page < doc["pages"].size()) {
            JsonArray pages = doc["pages"];
            JsonArray btns = pages[page]["buttons"];

            if (fromIdx >= 0 && toIdx >= 0 && fromIdx < btns.size() && toIdx < btns.size()) {

              // Swap buttons in JSON
              DynamicJsonDocument tmp(1024);
              tmp.set(btns[fromIdx]);
              btns[fromIdx] = btns[toIdx];
              btns[toIdx] = tmp.as<JsonVariant>();

              // Save config to SD (persistent)
              saveConfigToSD();

              // ÖNEMLİ: Bu sayfa ekranda ise, her şeyi baştan kur
              if (page == current_page) {
                draw_page(current_page);  // rebuilds current_buttons, timers, counters, toggles
              }

              Serial.println("BTN_SWAPPED_OK");
            } else {
              Serial.println("BTN_SWAPPED_FAIL");
            }
          } else {
            Serial.println("BTN_SWAPPED_FAIL");
          }
        }

        update_activity();
      }

      // --- Sleep Mode ---
      else if (command.startsWith("SET_SLEEP:")) {
        int mins = command.substring(10).toInt();
        if (mins > 0) {
          sleep_enabled = true;
          // Safe timeout calculation
          sleep_timeout_ms = (unsigned long)mins * 60 * 1000;

          preferences.putBool("sleep_on", true);
          preferences.putInt("sleep_min", mins);

          Serial.printf("Sleep enabled: %d min (Timeout: %lu ms)\n", mins, sleep_timeout_ms);
        } else {
          sleep_enabled = false;
          deep_sleep_enabled = false;  // Also disable deep sleep
          preferences.putBool("sleep_on", false);
          update_activity();
          Serial.println("Sleep disabled");
        }
        update_activity();  // Reset activity timer
      }

      // --- Deep Sleep Mode (screen & LED completely off) ---
      else if (command.startsWith("SET_DEEP_SLEEP:")) {
        int mins = command.substring(15).toInt();
        if (mins > 0) {
          deep_sleep_enabled = true;
          deep_sleep_timeout_ms = (unsigned long)mins * 60 * 1000;

          preferences.putBool("deep_sleep_on", true);
          preferences.putInt("deep_sleep_min", mins);

          Serial.printf("Deep Sleep enabled: %d min after dim\n", mins);
        } else {
          deep_sleep_enabled = false;
          preferences.putBool("deep_sleep_on", false);
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

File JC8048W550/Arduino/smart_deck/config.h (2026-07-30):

/*******************************************************************************
 * config.h - SmartDeck Hardware Configuration
 *
 * Pin definitions, display selection and layout constants.
 * Grid layout is auto-calculated based on SCREEN_INCH.
 ******************************************************************************/

#ifndef CONFIG_H
#define CONFIG_H

//=============================================================================
// DEVICE INFO
//=============================================================================
#define DEVICE_NAME   "Smart Deck"

//=============================================================================
// DISPLAY SELECTION (uncomment ONE)
//=============================================================================
// #define ESP32_3248S035       // 3.5" 480x320 (ST7796 SPI)
// #define ESP32_JC8048W550     // Guition JC8048W550 - 5" 800x480 (RGB)
// #define ESP32_8048S070       // 7.0" 800x480 (RGB)
#define ESP32_TOUCHDOWN        // Dustin Watts ESP32 TouchDown - 3.5" 480x320 (ILI9488)

//=============================================================================
// SCREEN SETTINGS
//=============================================================================
#if defined(ESP32_TOUCHDOWN)
  #define SCREEN_INCH       3
  #define SCREEN_WIDTH      480
  #define SCREEN_HEIGHT     320
  #define SCREEN_ROTATION   1       // Landscape (480x320)
#else
  #define SCREEN_INCH       5       // 3, 5, or 7 (affects grid layout)
  #define SCREEN_WIDTH      800
  #define SCREEN_HEIGHT     480
  #define SCREEN_ROTATION   0       // 0, 1, 2, 3 (0°, 90°, 180°, 270°)
#endif

//=============================================================================
// TOUCH SETTINGS
//=============================================================================
#define TOUCH_ROTATION    ROTATION_INVERTED   // ROTATION_NORMAL, ROTATION_INVERTED

//=============================================================================
// GRID LAYOUT (Auto-calculated based on SCREEN_INCH)
//=============================================================================
#if SCREEN_INCH == 3
  #define CELL_W              80
  #define CELL_H              80
  #define CELL_PADDING        10
  #define CORNER_RADIUS       20
  #define TITLE_BOX_HEIGHT    15
  #define TITLE_BOX_MARGIN_Y  2
  #define STROKE_WIDTH        2
#elif SCREEN_INCH == 5
  #define CELL_W              110
  #define CELL_H              110
  #define CELL_PADDING        17
  #define CORNER_RADIUS       20
  #define TITLE_BOX_HEIGHT    35
  #define TITLE_BOX_MARGIN_Y  3
  #define STROKE_WIDTH        2
#elif SCREEN_INCH == 7
  #define CELL_W              90
  #define CELL_H              90
  #define CELL_PADDING        17
  #define CORNER_RADIUS       15
  #define TITLE_BOX_HEIGHT    35
  #define TITLE_BOX_MARGIN_Y  3
  #define STROKE_WIDTH        2
#else
  #error "Invalid SCREEN_INCH! Use 3, 5, or 7"
#endif

//=============================================================================
// TOUCH PANEL PINS
//=============================================================================
#if defined(ESP32_TOUCHDOWN)
  // FT6236 (I2C) - ESP32 TouchDown
  #define TOUCH_SDA         21
  #define TOUCH_SCL         22
  #define TOUCH_INT         27
  #define TOUCH_WIDTH       SCREEN_WIDTH
  #define TOUCH_HEIGHT      SCREEN_HEIGHT
#else
  // GT911 - Guition / Sunton displays
  #define TOUCH_SDA         19
  #define TOUCH_SCL         20
  #define TOUCH_INT         0
  #define TOUCH_RST         38
  #define TOUCH_WIDTH       SCREEN_WIDTH
  #define TOUCH_HEIGHT      SCREEN_HEIGHT
#endif

//=============================================================================
// SD CARD
//=============================================================================
#if defined(ESP32_TOUCHDOWN)
  #define SD_CS             25
  #define SD_SCK            18
  #define SD_MISO           19
  #define SD_MOSI           23
#else
  #define SD_CS             10
#endif

//=============================================================================
// NEOPIXEL LED (optional external ring on broken-out GPIO)
//=============================================================================
#if defined(ESP32_TOUCHDOWN)
  #define LED_PIN           13
#else
  #define LED_PIN           18
#endif
#define LED_COUNT         16
#define LED_OFFSET        0   // LED ring rotation offset in degrees (0-359)

//=============================================================================
// ROTARY ENCODER (AS5600) - shares I2C bus with touch on TouchDown
//=============================================================================
#if defined(ESP32_TOUCHDOWN)
  #define KNOB_SDA          21
  #define KNOB_SCL          22
#else
  #define KNOB_SDA          17
  #define KNOB_SCL          19
#endif
#define KNOB_THRESHOLD    25
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

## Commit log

2025-12-08 Guition ESP32 compatible codes JC8048W550
2025-12-13 Update 3d_print_files and JC8048W550 folders
    [40_DEGREE_LEG.3mf]
